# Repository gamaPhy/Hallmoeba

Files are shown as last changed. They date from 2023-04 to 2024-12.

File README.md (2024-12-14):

# Hallmoeba

This repository contains assets for the Hallmoeba, a single-switch PCB for Gateron's KS-20 Hall effect switch. It is also compatible with Wooting's Lekker switch, which is based on the KS-20.

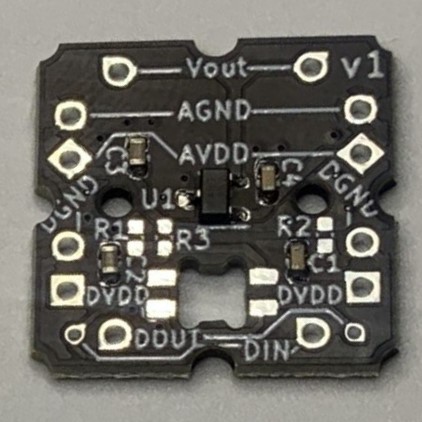
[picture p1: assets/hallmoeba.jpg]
Hallmoeba


## DIY Breadboard analog keypad made with Hallmoeba
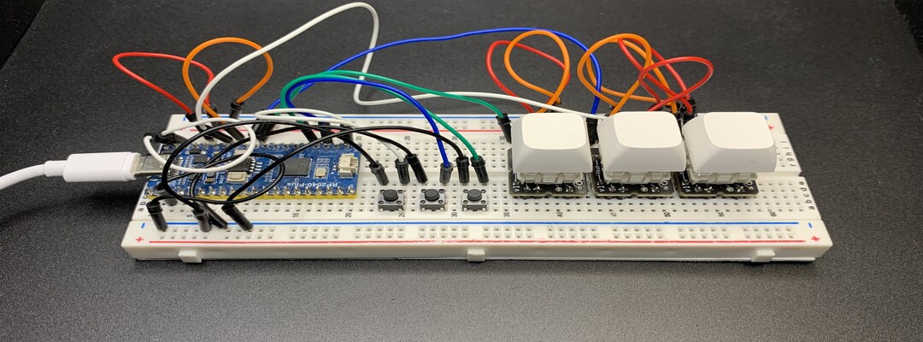
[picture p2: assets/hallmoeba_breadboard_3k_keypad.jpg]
Breadboard 3k Keypad


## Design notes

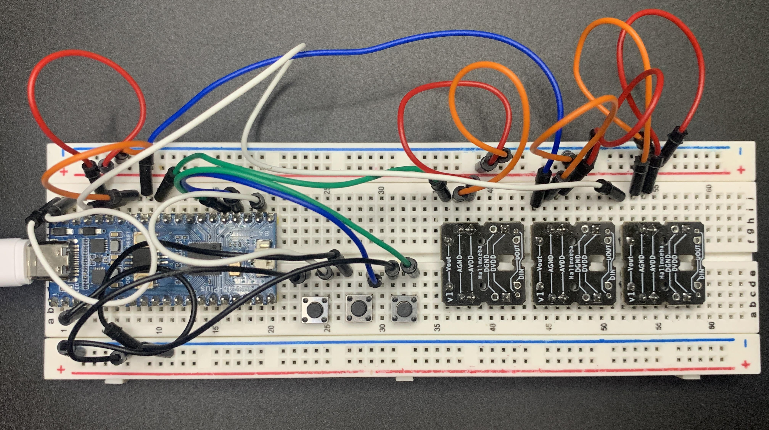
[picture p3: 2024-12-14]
assets/breadboard-keypad-top.jpg

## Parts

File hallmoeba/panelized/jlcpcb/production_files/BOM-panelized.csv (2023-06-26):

Comment | Designator | Footprint | LCSC
R | R2 | R_0402_1005Metric_Pad0.72x0.64mm_HandSolder
Conn_01x01_Pin | J9 | PinHeader_1x01_P2.54mm_Vertical
Conn_01x01_Pin | J6 | PinHeader_1x01_P2.54mm_Vertical
Conn_01x01_Pin | J2 | PinHeader_1x01_P2.54mm_Vertical
R | R1 | R_0402_1005Metric_Pad0.72x0.64mm_HandSolder
R | R3 | R_0402_1005Metric_Pad0.72x0.64mm_HandSolder
Conn_01x01_Pin | J8 | PinHeader_1x01_P2.54mm_Vertical
Conn_01x01_Pin | J12 | PinHeader_1x01_P2.54mm_Vertical
10u | C3 | C_0603_1608Metric
Conn_01x01_Pin | J3 | PinHeader_1x01_P2.54mm_Vertical
Conn_01x01_Pin | J5 | PinHeader_1x01_P2.54mm_Vertical
Conn_01x01_Pin | J1 | PinHeader_1x01_P2.54mm_Vertical
SK6812MINI-E | D1 | SK6812MINI_E
SLSS49E | U1 | SOT-23-3
Conn_01x01_Pin | J10 | PinHeader_1x01_P2.54mm_Vertical
Conn_01x01_Pin | J7 | PinHeader_1x01_P2.54mm_Vertical
Conn_01x01_Pin | J14 | PinHeader_1x01_P2.54mm_Vertical
Conn_01x01_Pin | J11 | PinHeader_1x01_P1.27mm_Vertical
10u | C2 | C_0603_1608Metric
100n | C4 | C_0603_1608Metric
100n | C1 | C_0603_1608Metric
Conn_01x01_Pin | J13 | PinHeader_1x01_P1.27mm_Vertical
Conn_01x01_Pin | J4 | PinHeader_1x01_P2.54mm_Vertical

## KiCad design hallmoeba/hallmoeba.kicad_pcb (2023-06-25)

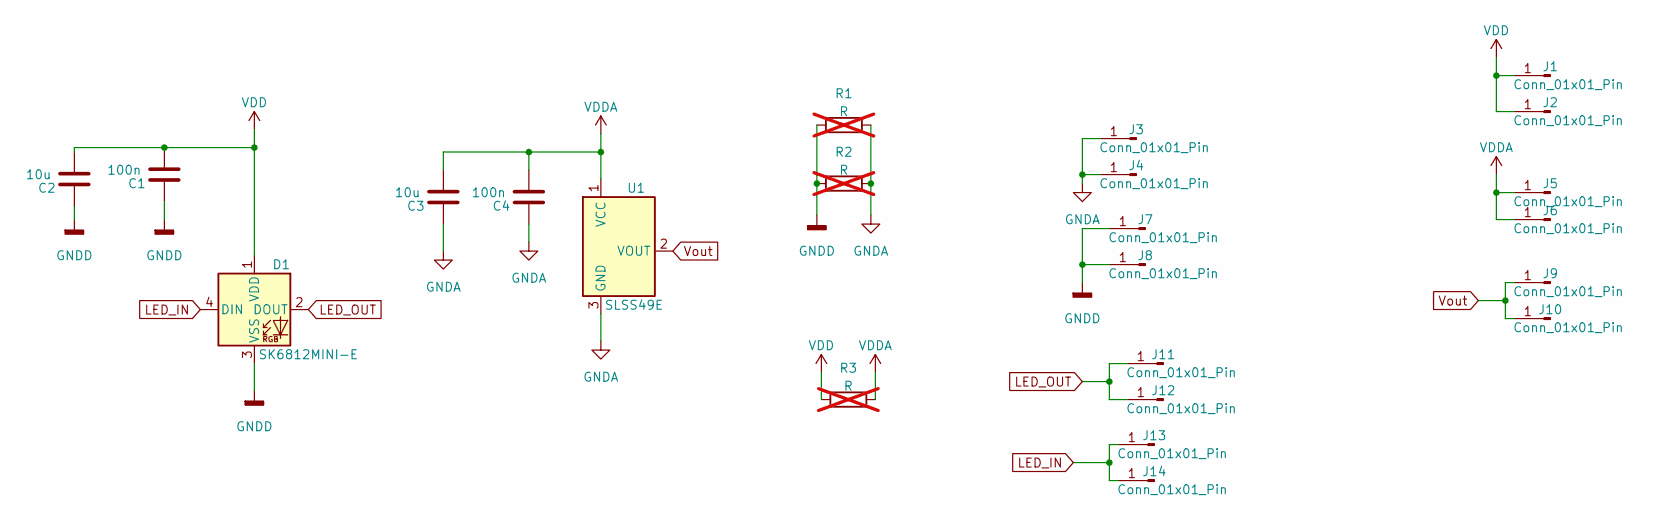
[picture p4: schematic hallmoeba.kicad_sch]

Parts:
C1, C4: 100n; C_0603_1608Metric
C2, C3: 10u; C_0603_1608Metric
D1: SK6812MINI-E; SK6812MINI_E
J1, J2, J3, J4, J5, J6, J7, J8, J9, J10, J12, J14: Conn_01x01_Pin; PinHeader_1x01_P2.54mm_Vertical
J11, J13: Conn_01x01_Pin; PinHeader_1x01_P1.27mm_Vertical
R1, R2, R3: R; R_0402_1005Metric_Pad0.72x0.64mm_HandSolder; not fitted
U1: SLSS49E; SOT-23-3

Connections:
GNDA: C3.1, C4.1, J3.1, J4.1, R1.2, R2.2, U1.3 (GND)
GNDD: C1.1, C2.1, D1.3 (VSS), J7.1, J8.1, R1.1, R2.1
LED_IN: D1.4 (DIN), J13.1, J14.1
LED_OUT: D1.2 (DOUT), J11.1, J12.1
VDD: C1.2, C2.2, D1.1 (VDD), J1.1, J2.1, R3.1
VDDA: C3.2, C4.2, J5.1, J6.1, R3.2, U1.1 (VCC)
Vout: J9.1, J10.1, U1.2 (VOUT)

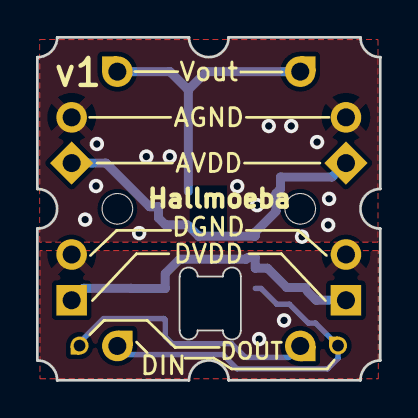
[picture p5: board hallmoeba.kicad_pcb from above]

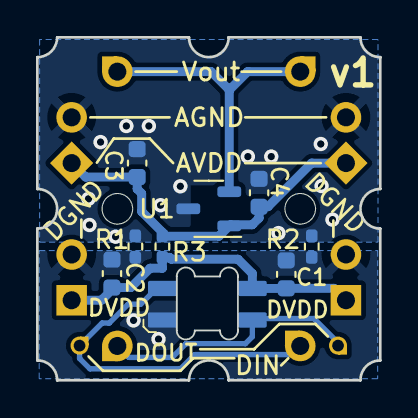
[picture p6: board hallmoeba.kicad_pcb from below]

Board: 2 copper layers, 19.1 x 19.0 mm, 24 parts (23 on the bottom side), 7 nets.

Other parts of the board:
SW: SW_Lekker_MX_1.00u_PCB

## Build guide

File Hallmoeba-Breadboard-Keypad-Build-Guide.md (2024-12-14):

# QMK-Powered Breadboard Keypad with Rapid Trigger \[RP2040 Build Guide\]

Assembled Hallmoeba Breadboard Keypad

### **Required Components:**

*   Breadboard-ready Hallmoebas
*   [Gateron Magnetic Switches](https://www.gateron.com/products/gateron-ks-20-magnetic-white-switch-set?VariantsId=10680) 
*   Keycaps
*   [830-point Breadboard](https://www.google.com/search?q=830+point+breadboard)
*   RP2040 MCU Board + Corresponding USB cable ([RP-Pico](https://www.raspberrypi.com/products/raspberry-pi-pico/) uses microUSB, but USB-C breakouts for the RP2040 can be found.)
*   [Male to Male Jumper Wires](https://www.google.com/search?q=male+to+male+jumper+wires)
*   [Through-hole SPST Tactile Switches  
    ](https://www.google.com/search?q=through+hole+spst+tactile+switch)\*If you don't want to buy buttons, you can also use open-ended wires connected to the MCU and pull those to ground whenever you want to "press" a button.  
*   Adhesive to hold the magnetic switches onto the Hallmoebas, since the switches cannot be soldered. We recommend a washable adhesive such as [Elmer's washable school glue](https://www.google.com/search?q=elmer%27s+washable+school+glue) so that the components can be reused. 
*   (_Optional_) Non-slip rubber stickers to keep the keypad from moving  

### **Wiring**

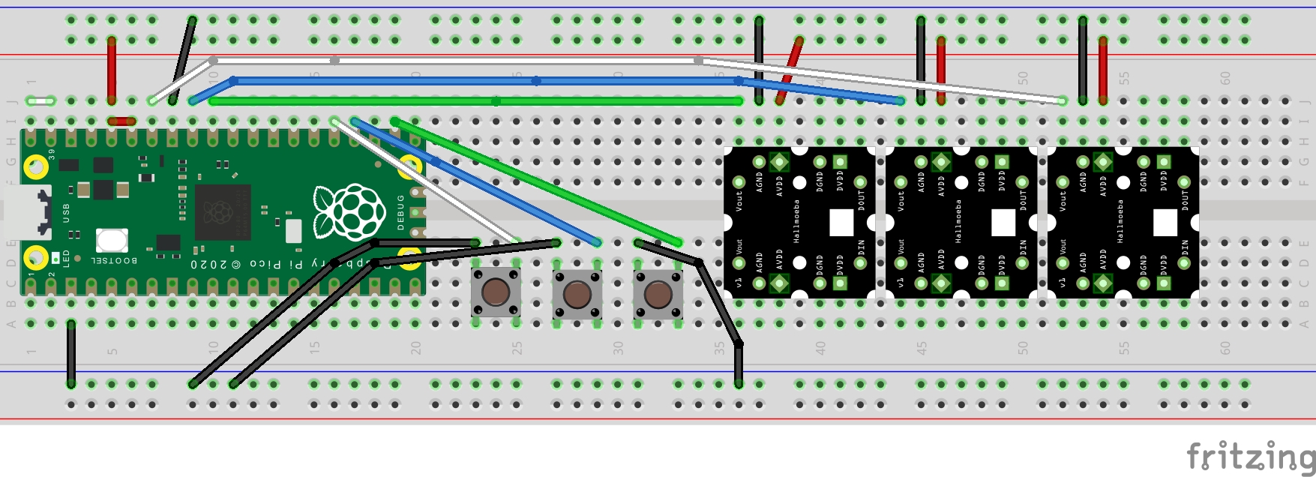
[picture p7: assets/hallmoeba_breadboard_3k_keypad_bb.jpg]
breadboard analog keypad fritzing wiring diagram


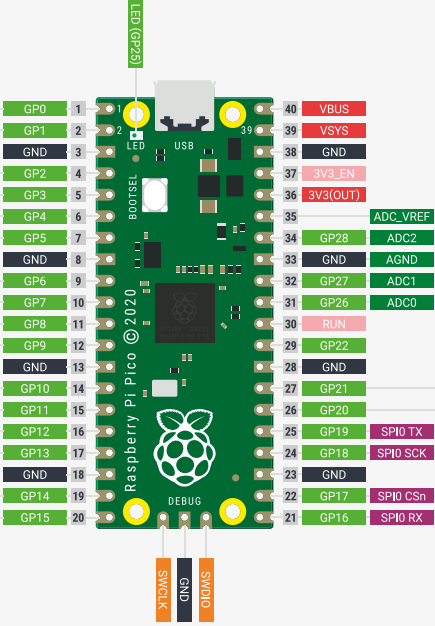
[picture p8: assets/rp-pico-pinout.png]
rp pico pinout
  

### **Firmware**

Download: [https://raw.githubusercontent.com/gamaPhy/qmk-keyboards/main/release/freedom/3k/via/gamaphy\_freedom\_3k\_via.uf2](https://raw.githubusercontent.com/gamaPhy/qmk-keyboards/main/release/freedom/3k/via/gamaphy_freedom_3k_via.uf2)

Source: [https://github.com/gamaPhy/qmk-keyboards/releases/tag/latest](https://github.com/gamaPhy/qmk-keyboards/releases/tag/latest)

### **Keypad Calibration**

1.  Load the firmware onto the RP-2040 board
2.  While keeping the calibration button held down (right button), press all the keys through their maximum range of motion. The LED on the Pico will turn on while in calibration mode, and will turn off after calibration is computed.
3.  Release the calibration button

### **(Optional) Reading Keypad Debug Logs**

1.  Download [qmk toolbox](https://github.com/qmk/qmk_toolbox/releases)
2.  Start qmk toolbox, and open the HID Console 
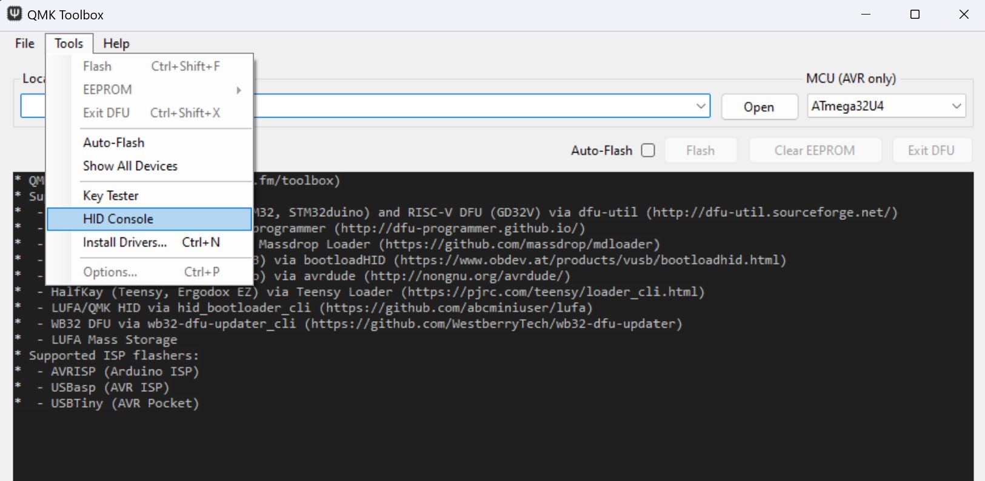
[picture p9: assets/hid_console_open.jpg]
hid console open
    
3.  You should see debug messages in the HID console. 
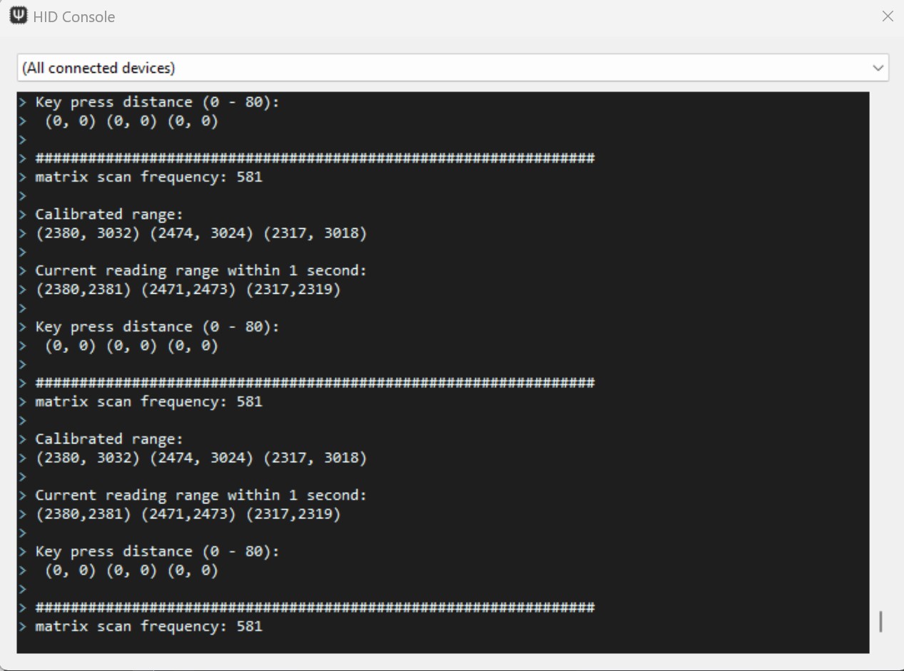
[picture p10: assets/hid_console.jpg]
hid console
    

### **Configuration Instructions**

1.  Use the [VIA webapp  
    ](https://usevia.app/ "via webapp")\*Or if you prefer not using web-serial, download VIA from source: [https://github.com/the-via/releases/releases](https://github.com/the-via/releases/releases)
2.  Download the following VIA draft file by right-clicking, and pressing "Save link as...":  
                  [https://raw.githubusercontent.com/gamaPhy/qmk-keyboards/main/release/freedom/3k/via/via.json](https://raw.githubusercontent.com/gamaPhy/qmk-keyboards/main/release/freedom/3k/via/via.json)
3.  Navigate to the "design" tab (paintbrush icon) of the VIA webapp, and load the following via draft file. After loading the draft file, the menu should look like this:  
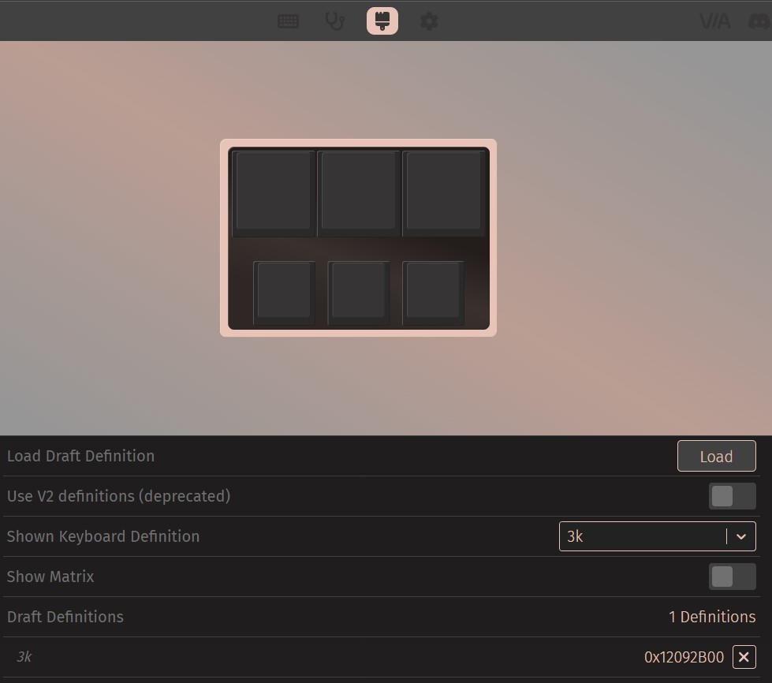
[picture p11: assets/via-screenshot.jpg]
via design tab
                                      
4.  Navigate to the "Configure" tab and select the IC icon in the bottom left to change actuation settings. (_There may be more settings present for you if the \`via.json\` was updated since the creation of these instructions_)  
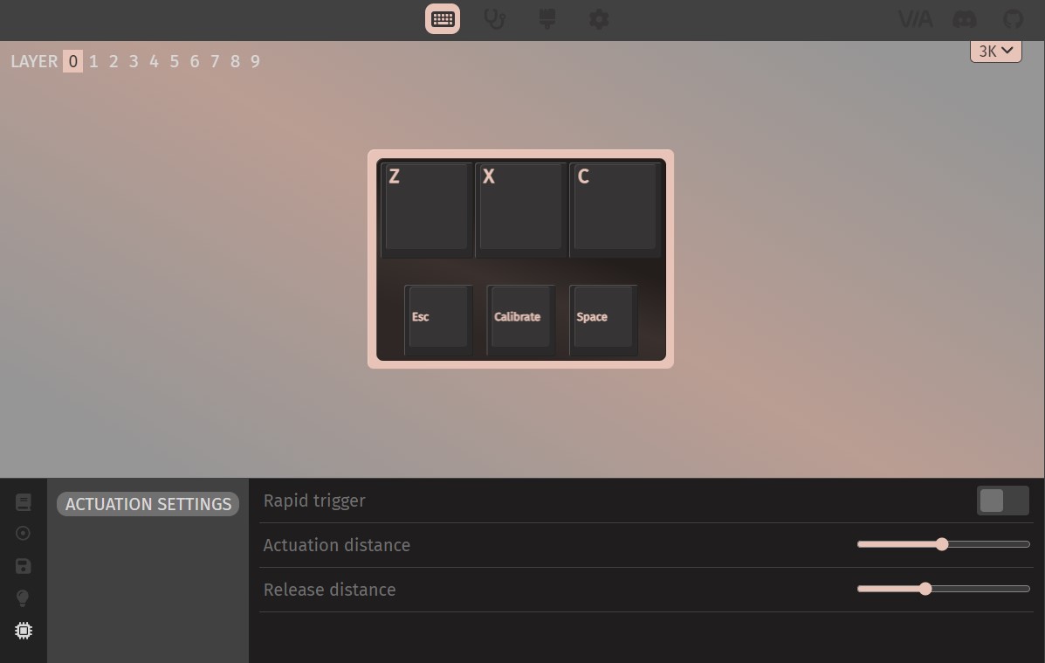
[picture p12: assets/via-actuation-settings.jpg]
via actuation settings
                                    

### **Debugging**

*   If the keypad is spamming keys even after calibration, the firmware may be corrupted. To fix this, follow [RasberryPi's instructions on resetting flash memory](https://www.raspberrypi.com/documentation/microcontrollers/raspberry-pi-pico.html#resetting-flash-memory).
*   The hall effect sensors are sensitive to temperature drift. Temperature drift compensation has not been implemented, so if the ambient temperature changes by too much, the board may need to be recalibrated. To see how much drift has occurred, you can look at the HID console to see how much the \`min calibrated range\` differs from the \`current reading range\` while keys are not pressed.
*   If the temperature drift is still a problem, the [DRV5056A3QDBZR](https://www.ti.com/lit/ds/symlink/drv5056.pdf?ts=1709848637493&ref_url=https%253A%252F%252Fwww.google.com%252F) hall-effect sensor may be better because it has temperature drift compensation built in.

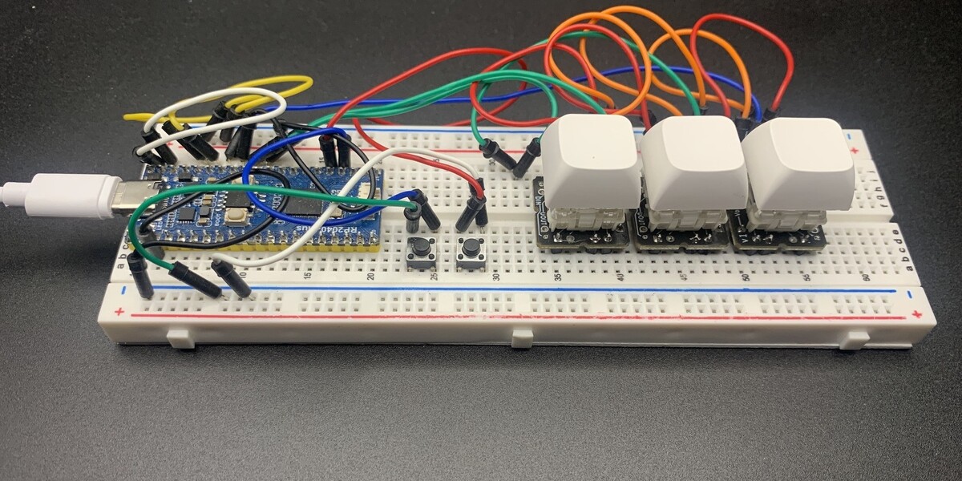
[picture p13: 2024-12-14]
assets/cropped-assembled-hallmoeba-breadboard-keypad.jpg

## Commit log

2023-03-27 Finish PCB
    [he-sensor-breakout-B_Cu.gbl, he-sensor-breakout-B_Mask.gbs, he-sensor-breakout-B_Paste.gbp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]
2023-03-28 makes sensor matrix
    [he-sensor-breakout.kicad_pcb, he-sensor-breakout.kicad_sch]
2023-03-28 removes vias within hall sensor
    [he-sensor-breakout.kicad_pcb]
2023-03-28 adds another row to matrix
    [he-sensor-breakout.kicad_pcb]
2023-03-28 adds more test fixtures
    [he-sensor-breakout.kicad_pcb]
2023-03-30 adds tb
    [he-sensor-breakout-CuBottom.gbr, he-sensor-breakout-CuTop.gbr, he-sensor-breakout-EdgeCuts.gbr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]
2023-03-30 finishing touches
    [he-sensor-breakout.kicad_pcb]
2023-03-30 adds vdd and vdd connection pads
    [he-sensor-breakout.kicad_pcb, he-sensor-breakout.kicad_sch]
2023-03-30 vdda and vdd connection
    [he-sensor-breakout.kicad_pcb, he-sensor-breakout.kicad_sch]
2023-03-30 moves holes and adds silkscreen
    [he-sensor-breakout.kicad_pcb]
2023-03-30 move tabs
    [he-sensor-breakout.kicad_pcb, tab.kicad_pcb]
2023-03-31 moves GND shorts
    [he-sensor-breakout.kicad_pcb, he-sensor-breakout.kicad_sch, tab.kicad_pcb]
2023-03-31 changes hole sizes to m1.6
    [he-sensor-breakout.kicad_pcb, tab.kicad_pcb]
2023-03-31 fix screw hole
    [he-sensor-breakout.kicad_pcb]
2023-03-31 fix tabs
    [tab.kicad_pcb]
2023-03-31 adds panelization tabs
    [he-sensor-breakout.kicad_pcb]
2023-03-31 changes tabs
    [he-sensor-breakout.kicad_pcb]
2023-03-31 adds 1x3 breadboard plate
    [1x3_breadboard_plate.kicad_pcb]
2023-04-01 shrink 1x1 and add 2u outline
    [1x3_breadboard_plate.kicad_pcb, he-sensor-breakout.kicad_pcb, stabilizer.kicad_pcb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]
2023-04-02 fixes kikit tabs
    [he-sensor-breakout.kicad_pcb]
2023-04-02 adds silkscreen to 1x1
    [he-sensor-breakout.kicad_pcb]
2023-04-02 fixes left and right tabs
    [tab.kicad_pcb]
2023-04-02 make symmetric
    [he-sensor-breakout.kicad_pcb, tab.kicad_pcb]
2023-04-02 fix edge cuts
    [1x3_breadboard_plate.kicad_pcb, he-sensor-breakout.kicad_pcb]
2023-04-02 remove duplicate tabs
    [he-sensor-breakout.kicad_pcb]
2023-04-03 move bottom trace up a bit
    [he-sensor-breakout.kicad_pcb]
2023-04-03 add custom kikit script for tabs and to fix mousebites
    [he-sensor-breakout.kicad_pcb, tab.kicad_pcb]
2023-04-03 make the 1u taller by a tiny bit
    [he-sensor-breakout.kicad_pcb, tab.kicad_pcb]
2023-04-03 tweak stabilizer to match 1u
    [stabilizer.kicad_pcb]
2023-04-03 rename stuff
    [2u_stabilizer.kicad_pcb, 2u_stabilizer.kicad_sch, he-sensor-breakout.kicad_pcb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]
2023-04-03 updates 1x3 breadboard plate for new dimensions
    [1x3_breadboard_plate.kicad_pcb]
2023-04-04 converts to 19.05x19.05mm
    [1x3_breadboard_plate.kicad_pcb, 2u_stabilizer.kicad_pcb, he-sensor-breakout.kicad_pcb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]
2023-04-04 fixes silkscreen
    [1u.kicad_pcb, 1u.kicad_sch]
2023-04-07 switch to vcuts
    [1u.kicad_pcb]
2023-04-07 remove 2u_stabilizer (moved to branch)
    [2u_stabilizer.kicad_pcb, 2u_stabilizer.kicad_sch]
2023-04-08 adds copyright notice
    [1u.kicad_pcb, 1u.kicad_sch]
2023-04-08 change pcb name
    [hallmoeba.kicad_pcb, hallmoeba.kicad_sch]
2023-04-18 change silkscreen
    [hallmoeba.kicad_pcb, tab.kicad_pcb]
2023-04-23 adds production files
    [1x3_breadboard_plate-CuBottom.gbr, 1x3_breadboard_plate-CuTop.gbr, 1x3_breadboard_plate-EdgeCuts.gbr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]
2023-06-25 increase mounting hole size to M2. remove tabs and plate
    [1x3_breadboard_plate-CuBottom.gbr, 1x3_breadboard_plate-CuTop.gbr, 1x3_breadboard_plate-EdgeCuts.gbr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]
2023-06-26 adds jlc prod files
    [panelized-EdgeCuts.gbr, panelized-MaskBottom.gbr, panelized-MaskTop.gbr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]
2023-06-26 changes gitignore to add all jlc prod files
    [BOM-panelized.csv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]
2023-09-21 adds fritzing related stuff
    [hallmoeba-breadboard-3k-keypad.fzz, hallmoeba_breadboard_3k_keypad.fzz]
2023-10-24 updates fritzing wiring to match keypad pcb
    [hallmoeba_breadboard_3k_keypad.fzz]
2023-12-02 connects 3v3 out to ADC_VREF in fritzing diagram to match up with Freedom-3k
    [hallmoeba_breadboard_3k_keypad.fzz]

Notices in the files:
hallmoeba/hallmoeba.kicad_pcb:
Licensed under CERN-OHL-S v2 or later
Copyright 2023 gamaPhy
